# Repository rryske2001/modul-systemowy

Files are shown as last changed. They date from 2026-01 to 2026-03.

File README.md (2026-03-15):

# Moduł Systemowy HD44780 LCD Driver & PCB Adapter Collection





## 📖 O projekcie

Niniejsze repozytorium zawiera kompleksowe rozwiązanie dla obsługi popularnych wyświetlaczy znakowych LCD opartych na sterowniku **HD44780**. Projekt składa się z dwóch głównych filarów:
1.  **Warstwa sprzętowa:** Projekty płytek drukowanych (PCB) wykonane w środowisku **KiCad**, służące jako adaptery i moduły interfejsowe dla wyświetlaczy 16x2, 20x4 oraz 40x2.
2.  **Warstwa programowa:** Biblioteki sterowników napisane w języku C, obsługujące różne tryby komunikacji (I2C, 4-bit, 8-bit) ze szczególnym naciskiem na optymalizację (odczyt flagi zajętości - Busy Flag).

---

## 🛠️ Funkcjonalności

### 🔌 Hardware (Projekty PCB)
Projekty płytek zostały przygotowane w programie **KiCad**. Repozytorium zawiera pliki produkcyjne oraz źródłowe dla kilku wariantów:
* **Wersje jedno- i dwuwarstwowe:** Dostosowane do różnych metod produkcji (domowe trawienie vs profesjonalna produkcja).
* **Uniwersalność:** Obsługa popularnych formatów wyświetlaczy: 16x2, 20x4 oraz 40x2.
* **Adaptery I2C:** Projekty integrujące ekspandery portów (np. PCF8574) bezpośrednio z wyświetlaczem, co redukuje liczbę wymaganych pinów mikrokontrolera.

### 💻 Software (Sterowniki)
Kod źródłowy zawiera implementację sterowników w różnych konfiguracjach sprzętowych:
* **Obsługa I2C:** Sterowanie poprzez ekspander (PCF8574), idealne dla systemów z ograniczoną liczbą GPIO.
* **Tryb równoległy (4-bit i 8-bit):** Klasyczne sterowanie bezpośrednie.
* **Busy Flag Check:** Zaimplementowany mechanizm odczytu flagi zajętości sterownika HD44780. Pozwala to na uniknięcie sztywnych opóźnień (`delay`), co znacząco zwiększa wydajność całego systemu wbudowanego.
* **Interfejs szeregowy:** Alternatywne metody komunikacji.

---

## 📂 Struktura Repozytorium

Poniżej znajduje się opis zawartości kluczowych katalogów:

### Projekty KiCad
* `/Wersja_z_I2C_8bit_...` - Projekt dwuwarstwowej płytki z integracją I2C.
* `/Wersja_16x2_20x4_...` - Uniwersalna płytka jednowarstwowa dla standardowych wyświetlaczy.
* `/wersja_ostateczna_wyswietlacz_pcf_v1` - Finalna wersja adaptera z układem PCF.

### Kod Źródłowy
* `/wyswietlacz_interfejs_4_bit_BusyFlag` - Sterownik 4-bitowy z odczytem BF.
* `/testy_z_ekspanderem_pcf` - Kod testowy dla komunikacji I2C.
* `/wyswietlacz_interfejs_8_bit` - Podstawowa obsługa w trybie 8-bitowym.

---

## 🔧 Technologie i Narzędzia

* **Projektowanie PCB:** KiCad EDA
* **Język programowania:** C (Embedded)
* **Hardware:** Wyświetlacze HD44780, Ekspandery PCF8574
* **Protokoły:** I2C, Parallel Interface

---

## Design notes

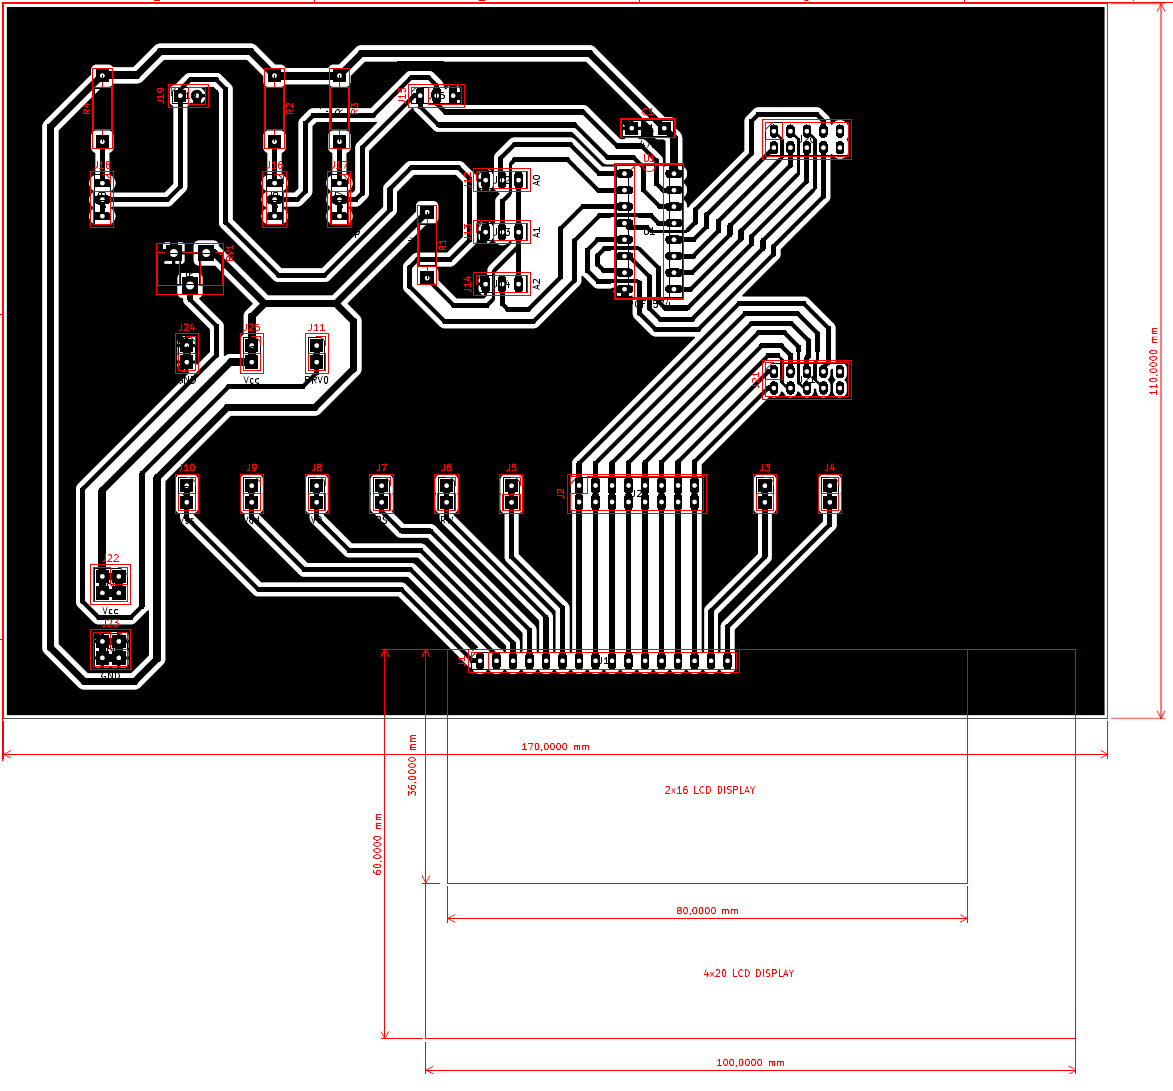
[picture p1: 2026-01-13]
plytki/wersja_ostateczna_wyswietlacz_pcf_v1/plots/wersja_ostateczna_wyswietlacz_pcf_v1.png

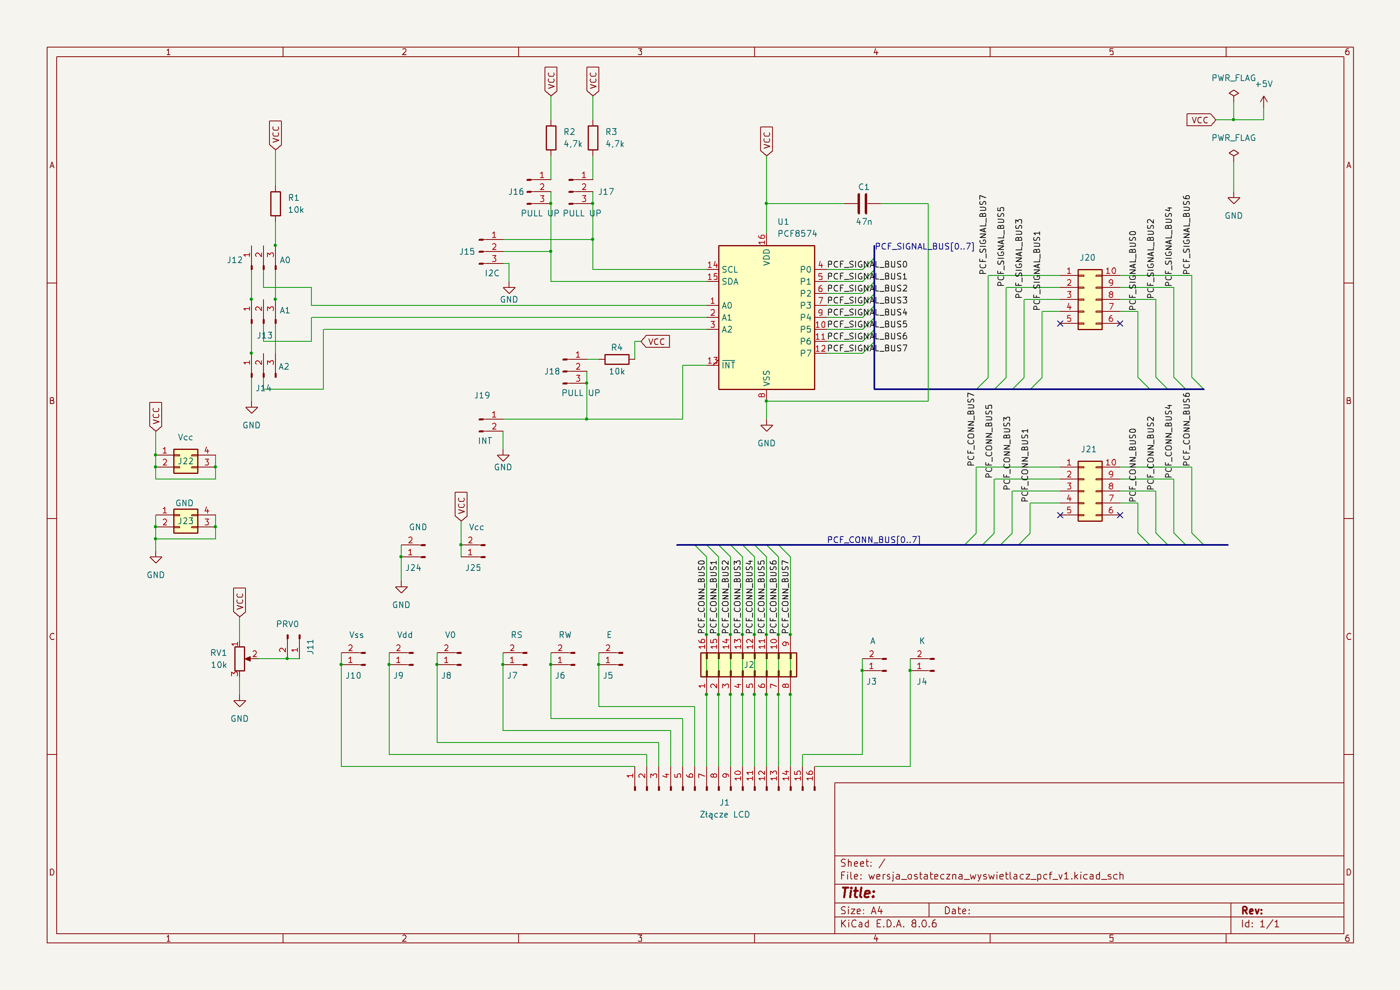
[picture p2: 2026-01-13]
plytki/wersja_ostateczna_wyswietlacz_pcf_v1/plots/wersja_ostateczna_wyswietlacz_pcf_v1_Schemat.png

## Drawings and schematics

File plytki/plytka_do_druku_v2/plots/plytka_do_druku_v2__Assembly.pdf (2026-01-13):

1 | 2 | 3 | 4 | 5 | 6

A

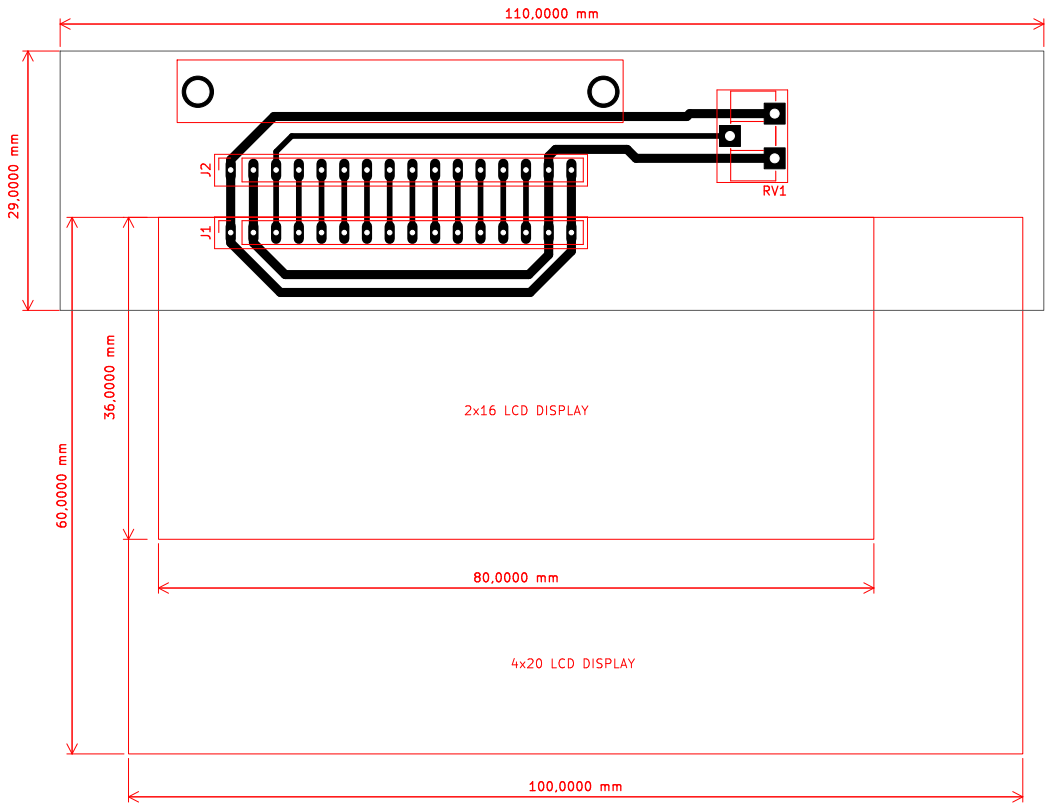
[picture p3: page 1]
D Date: KiCad; E.D.A. 8.0.6 Size: A4; Rev:; 2x16 LCD DISPLAY J2 J1

4x20 LCD DISPLAY ³⁶,0000 mm

Id: 1/1 Title: File: plytka_do_druku_v2.kicad_pcb Sheet:

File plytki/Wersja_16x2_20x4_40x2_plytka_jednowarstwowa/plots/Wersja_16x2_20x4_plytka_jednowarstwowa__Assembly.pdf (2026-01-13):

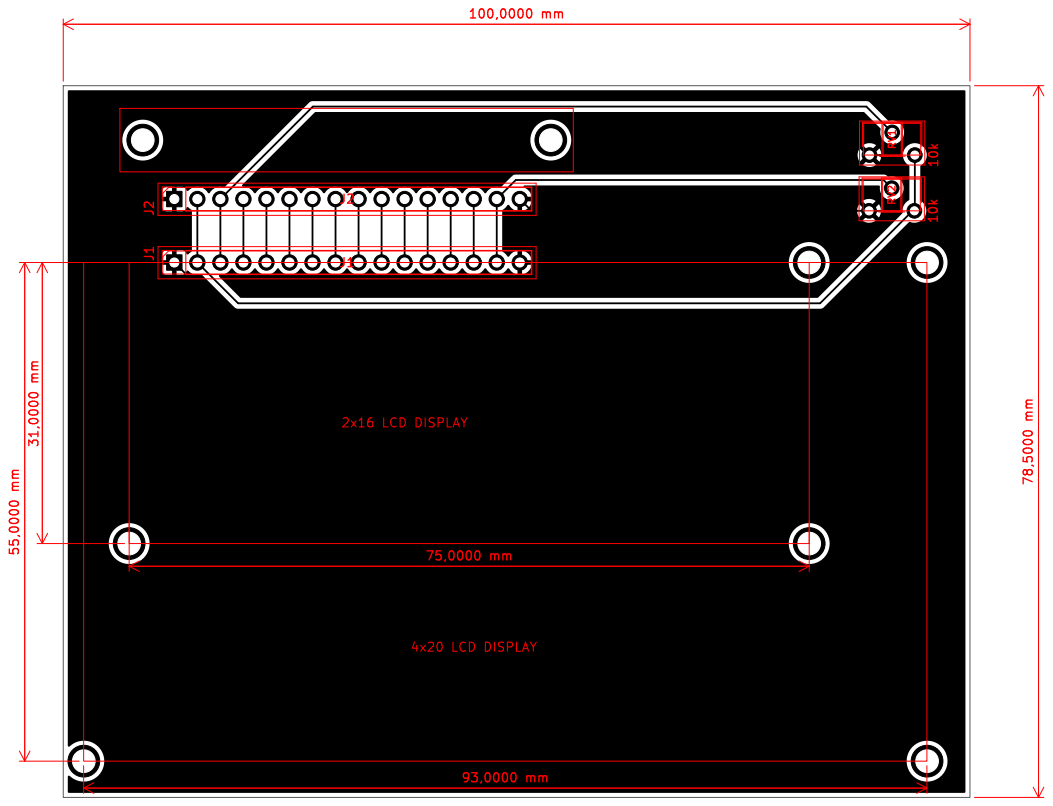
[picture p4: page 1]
D Date: KiCad; E.D.A. 8.0.6 Size: A4; Rev:; 10kRV¹; 10kRV² 4x20 LCD DISPLAY; 2x16 LCD DISPLAY J1 J2

Id: 1/1 Title: File: Wersja_16x2_20x4_plytka_jednowarstwowa.kicad_pcb Sheet:

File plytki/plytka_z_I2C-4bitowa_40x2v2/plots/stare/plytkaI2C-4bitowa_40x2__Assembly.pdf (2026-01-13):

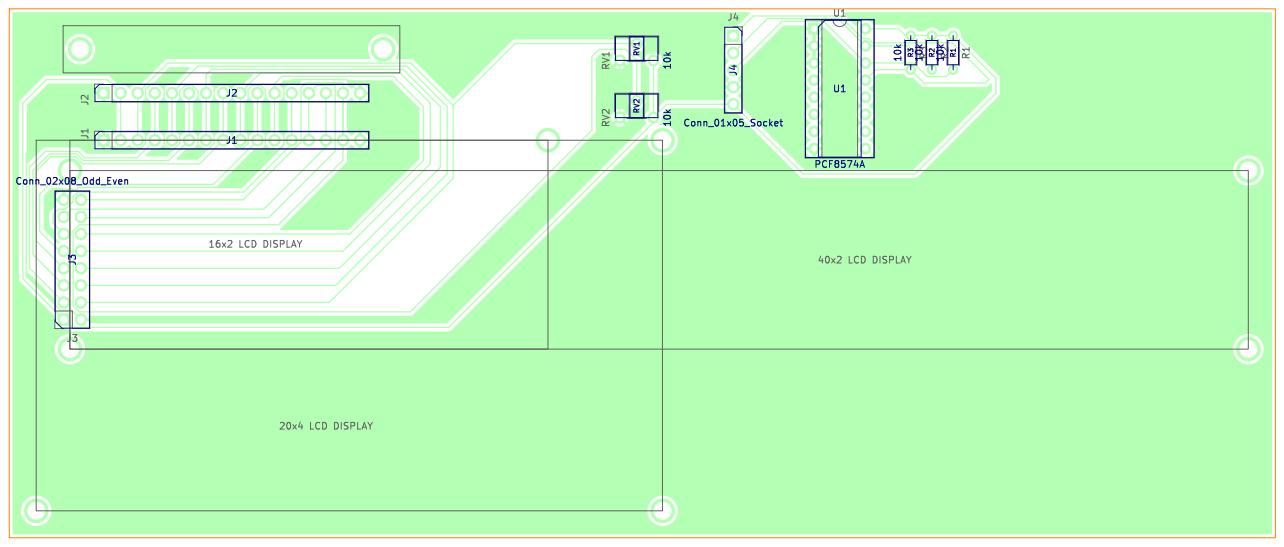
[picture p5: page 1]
40x2 LCD DISPLAY; 20x4 LCD DISPLAY; 16x2 LCD DISPLAY; RV² J2; RV¹; D Date: KiCad; E.D.A. 8.0.6 Size: A4; Rev:; Id: 1/1 Title: File: plytkaI2C-4bitowa_40x2.kicad_pcb Sheet: ¹⁰k; R¹ Conn_01x05_Socket J4; Conn_02x08_Odd_Even J3; 10kRV²; 10kRV¹; PCF8574A U1

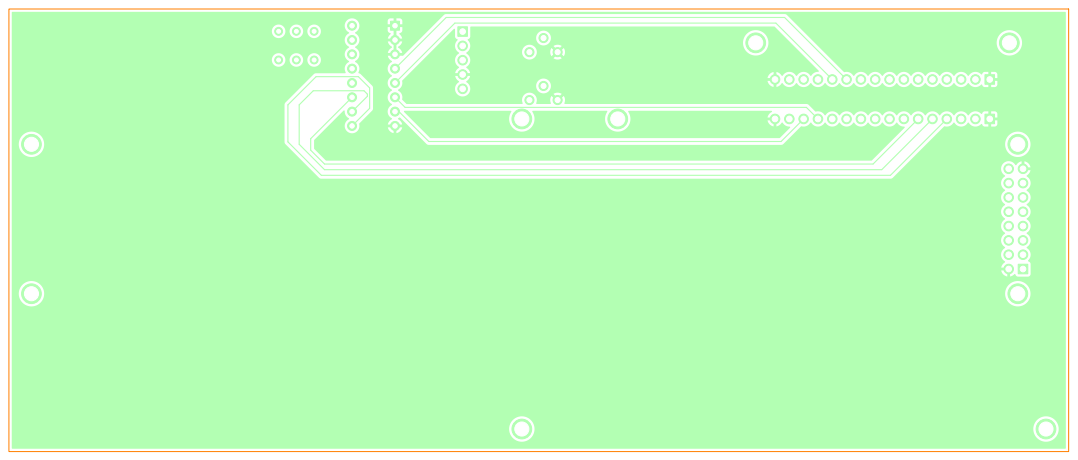
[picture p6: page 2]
D Date: KiCad; E.D.A. 8.0.6 Size: A4; Rev:

Id: 1/1 Title: File: plytkaI2C-4bitowa_40x2.kicad_pcb Sheet:

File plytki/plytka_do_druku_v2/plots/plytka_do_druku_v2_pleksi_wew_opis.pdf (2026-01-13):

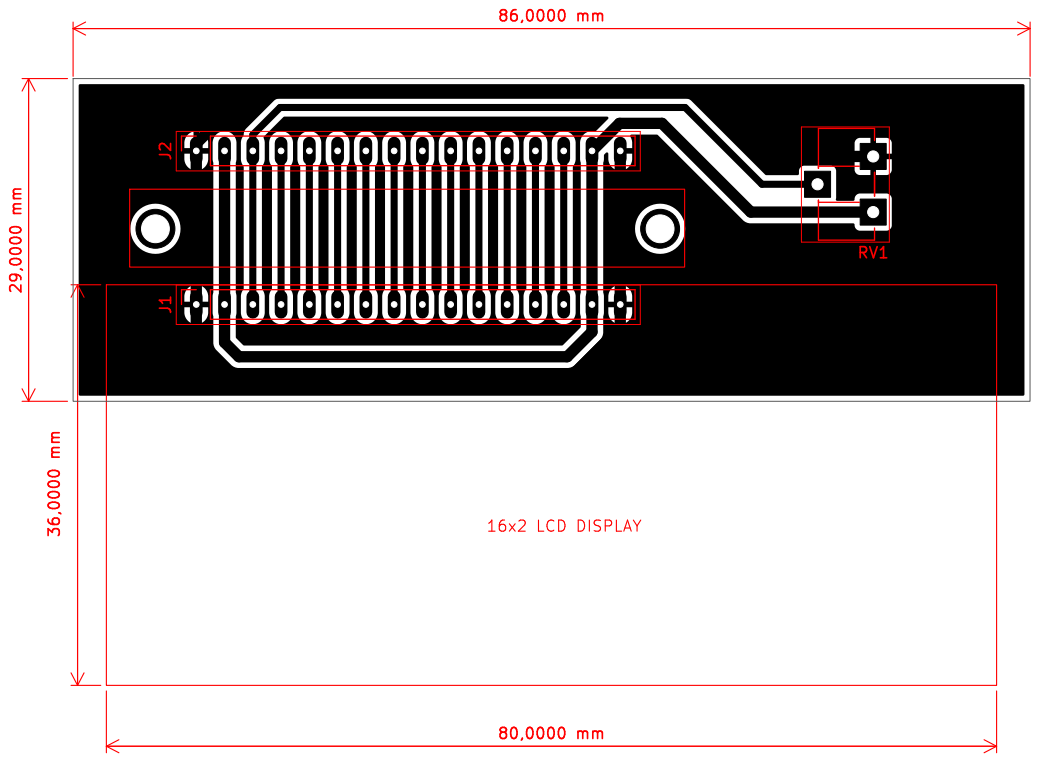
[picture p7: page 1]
D Date: KiCad; E.D.A. 8.0.6 Size: A4; Rev:; 16x2 LCD DISPLAY J2 J1

Id: 1/1 Title: File: plytka_do_druku_v2_pleksi_wew.kicad_pcb Sheet:

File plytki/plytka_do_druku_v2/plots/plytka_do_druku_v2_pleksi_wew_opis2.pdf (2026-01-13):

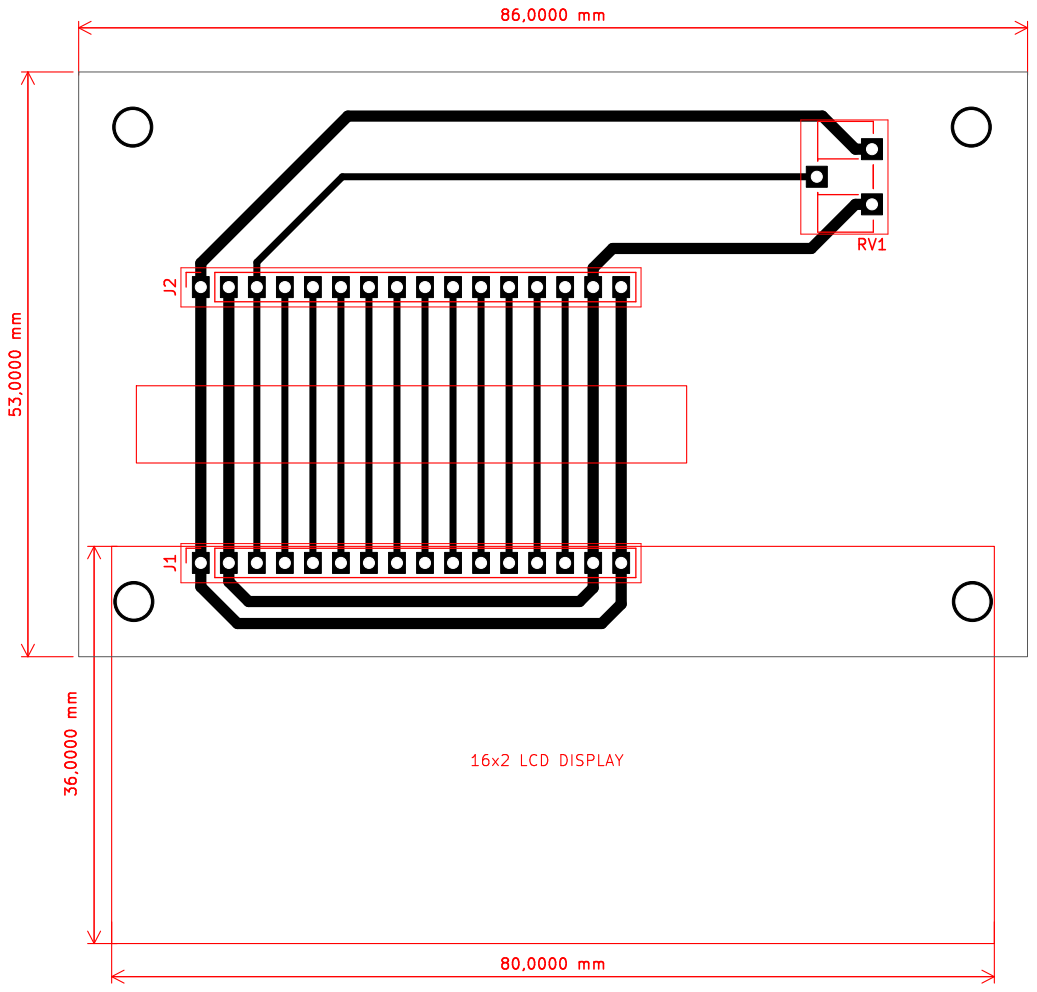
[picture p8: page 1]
D Date: KiCad; E.D.A. 8.0.6 Size: A4; Rev:; Id: 1/1 Title: File: plytka_do_druku_v2_pleksi_wew.kicad_pcb Sheet: ¹⁶x2 LCD DISPLAY J2 J1

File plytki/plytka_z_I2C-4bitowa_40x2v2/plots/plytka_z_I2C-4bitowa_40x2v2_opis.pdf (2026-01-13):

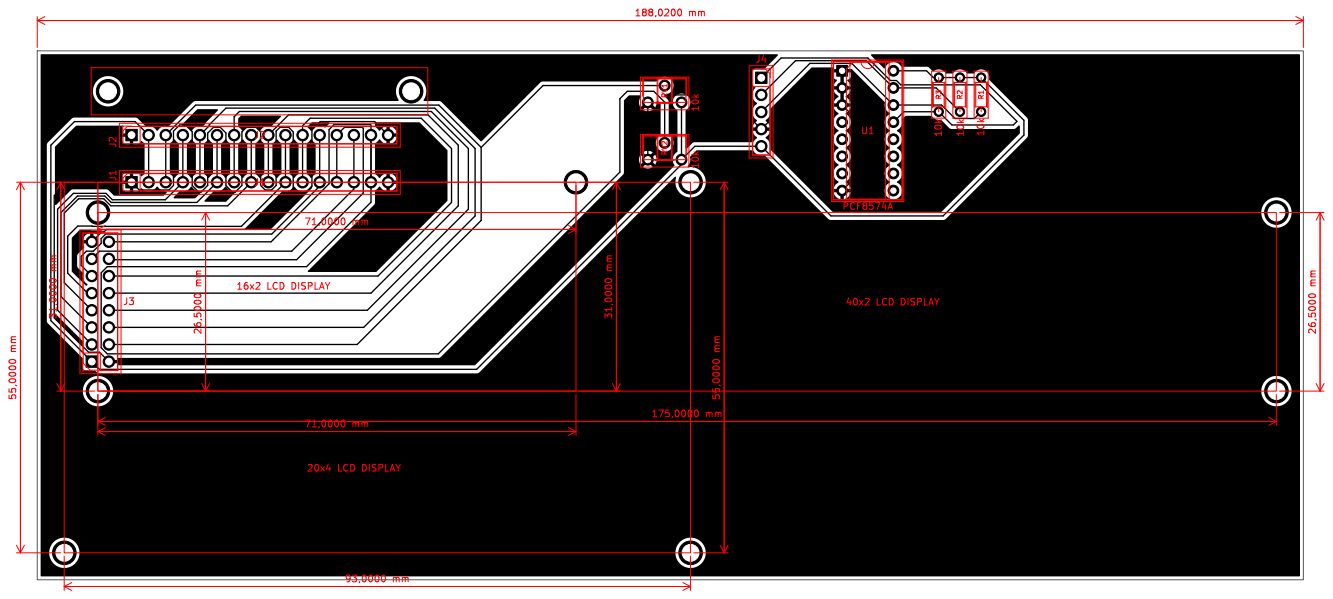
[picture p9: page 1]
D Date: KiCad; E.D.A. 8.0.6 Size: A4; Rev:; Id: 1/1 Title: File: plytka_z_I2C-4bitowa_40x2v2.kicad_pcb Sheet: ¹⁰k R³; 10kRV²; PCF8574A U1 J2; 10kRV¹; 10k R¹ 40x2 LCD DISPLAY; 20x4 LCD DISPLAY; 16x2 LCD DISPLAY

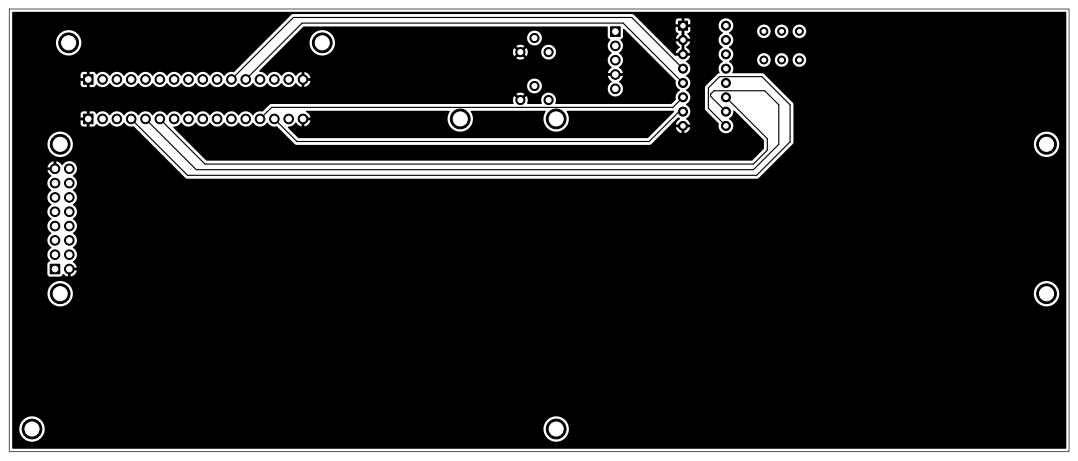
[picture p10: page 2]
D Date: KiCad; E.D.A. 8.0.6 Size: A4; Rev:

Id: 1/1 Title: File: plytka_z_I2C-4bitowa_40x2v2.kicad_pcb Sheet:

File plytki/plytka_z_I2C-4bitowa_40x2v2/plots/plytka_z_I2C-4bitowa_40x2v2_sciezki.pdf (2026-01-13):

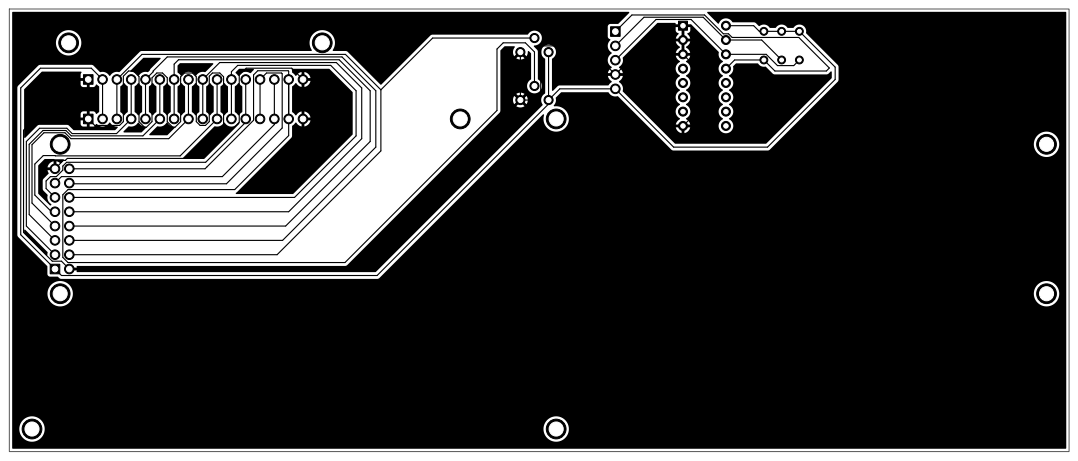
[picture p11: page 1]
D Date: KiCad; E.D.A. 8.0.6 Size: A4; Rev:

Id: 1/1 Title: File: plytka_z_I2C-4bitowa_40x2v2.kicad_pcb Sheet:

D Date: KiCad; E.D.A. 8.0.6 Size: A4; Rev:

Id: 1/1 Title: File: plytka_z_I2C-4bitowa_40x2v2.kicad_pcb Sheet:

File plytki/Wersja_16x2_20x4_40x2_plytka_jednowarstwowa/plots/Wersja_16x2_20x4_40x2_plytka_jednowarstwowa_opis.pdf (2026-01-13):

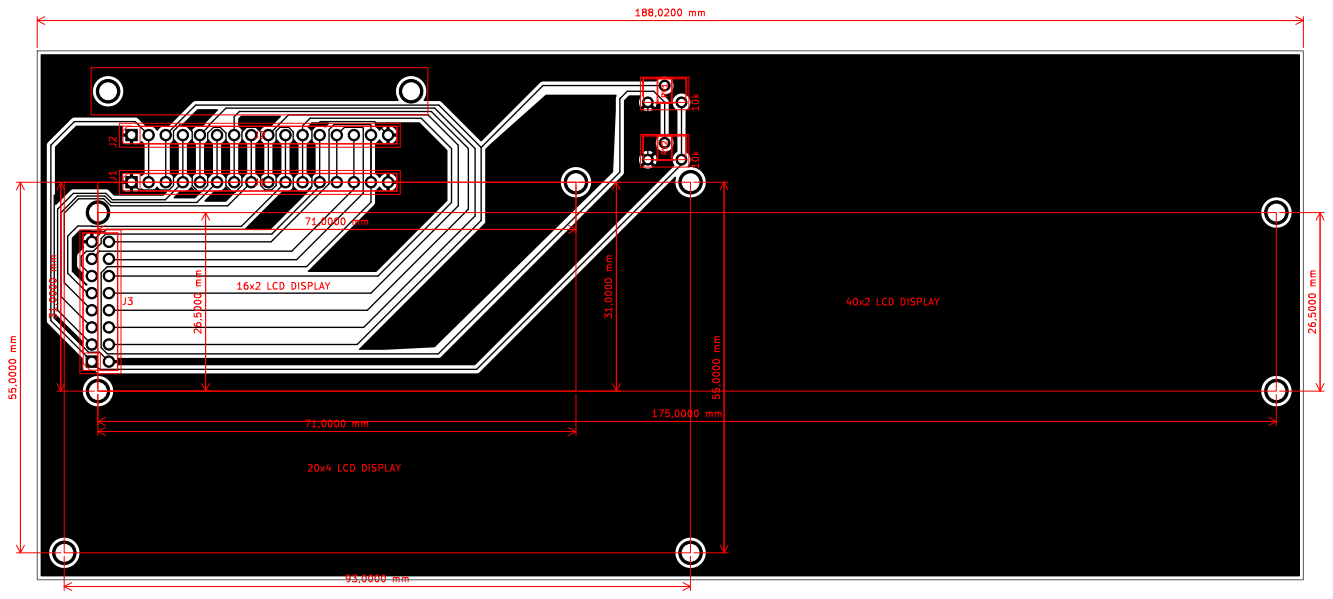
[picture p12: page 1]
D Date: KiCad; E.D.A. 8.0.6 Size: A4; Rev:; 10kRV²; 10kRV¹; 40x2 LCD DISPLAY; 20x4 LCD DISPLAY; 16x2 LCD DISPLAY

Id: 1/1 Title: File: Wersja_16x2_20x4_40x2_plytka_jednowarstwowa.kicad_pcb Sheet:

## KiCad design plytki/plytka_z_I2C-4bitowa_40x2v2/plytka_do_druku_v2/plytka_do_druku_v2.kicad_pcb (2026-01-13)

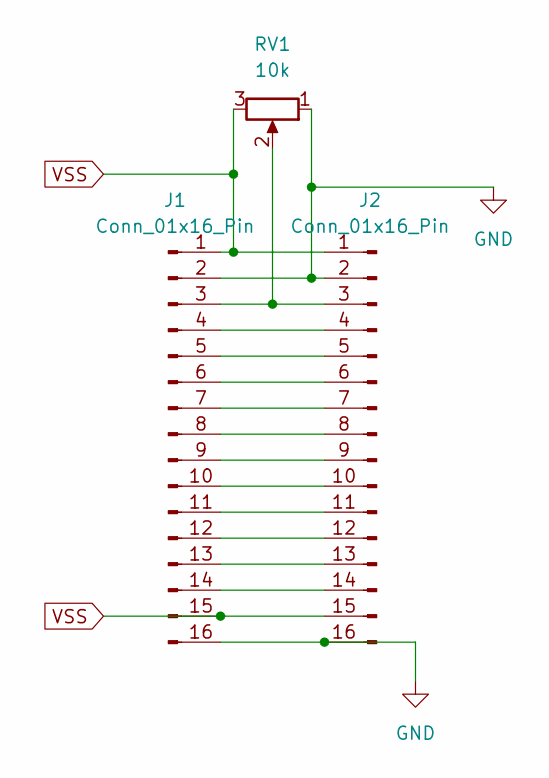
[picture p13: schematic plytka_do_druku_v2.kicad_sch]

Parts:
J1: Conn_01x16_Pin; PinSocket_1x16_P2.54mm_Vertical
J2: Conn_01x16_Pin; waski
RV1: 10k; Potentiometer_Alps_RK09Y11_Single_Horizontal

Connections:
GND: J1.2, J1.16, J2.2, J2.16, RV1.1
unnamed: J1.3, J2.3, RV1.2
unnamed: J1.4, J2.4
unnamed: J1.5, J2.5
unnamed: J1.6, J2.6
unnamed: J1.7, J2.7
unnamed: J1.8, J2.8
unnamed: J1.9, J2.9
unnamed: J1.10, J2.10
unnamed: J1.11, J2.11
unnamed: J1.12, J2.12
unnamed: J1.13, J2.13
unnamed: J1.14, J2.14
VSS: J1.1, J1.15, J2.1, J2.15, RV1.3

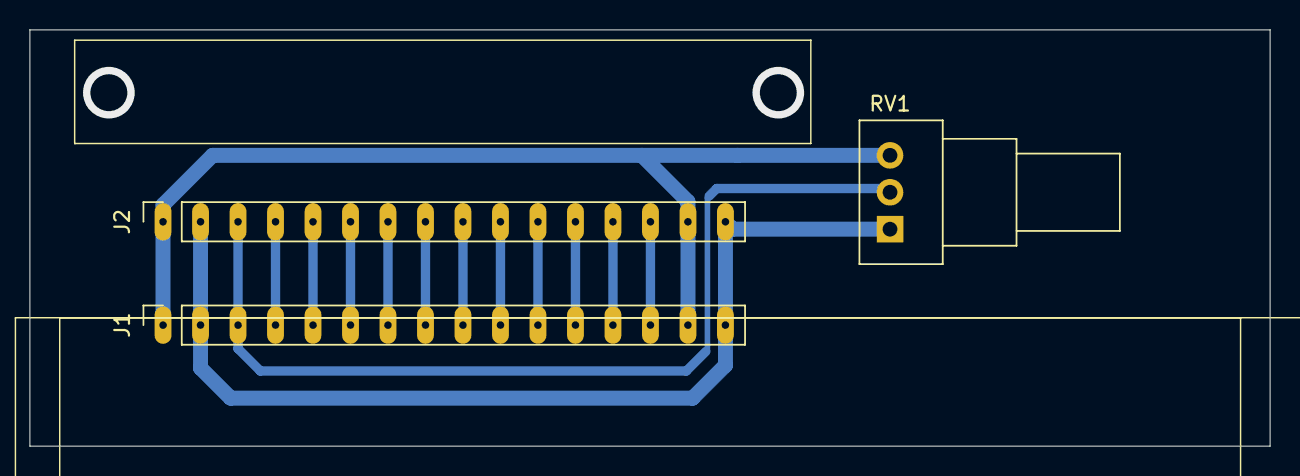
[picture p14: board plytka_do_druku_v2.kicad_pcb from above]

Board: 2 copper layers, 84.0 x 28.2 mm, 3 parts (0 on the bottom side), 14 nets.

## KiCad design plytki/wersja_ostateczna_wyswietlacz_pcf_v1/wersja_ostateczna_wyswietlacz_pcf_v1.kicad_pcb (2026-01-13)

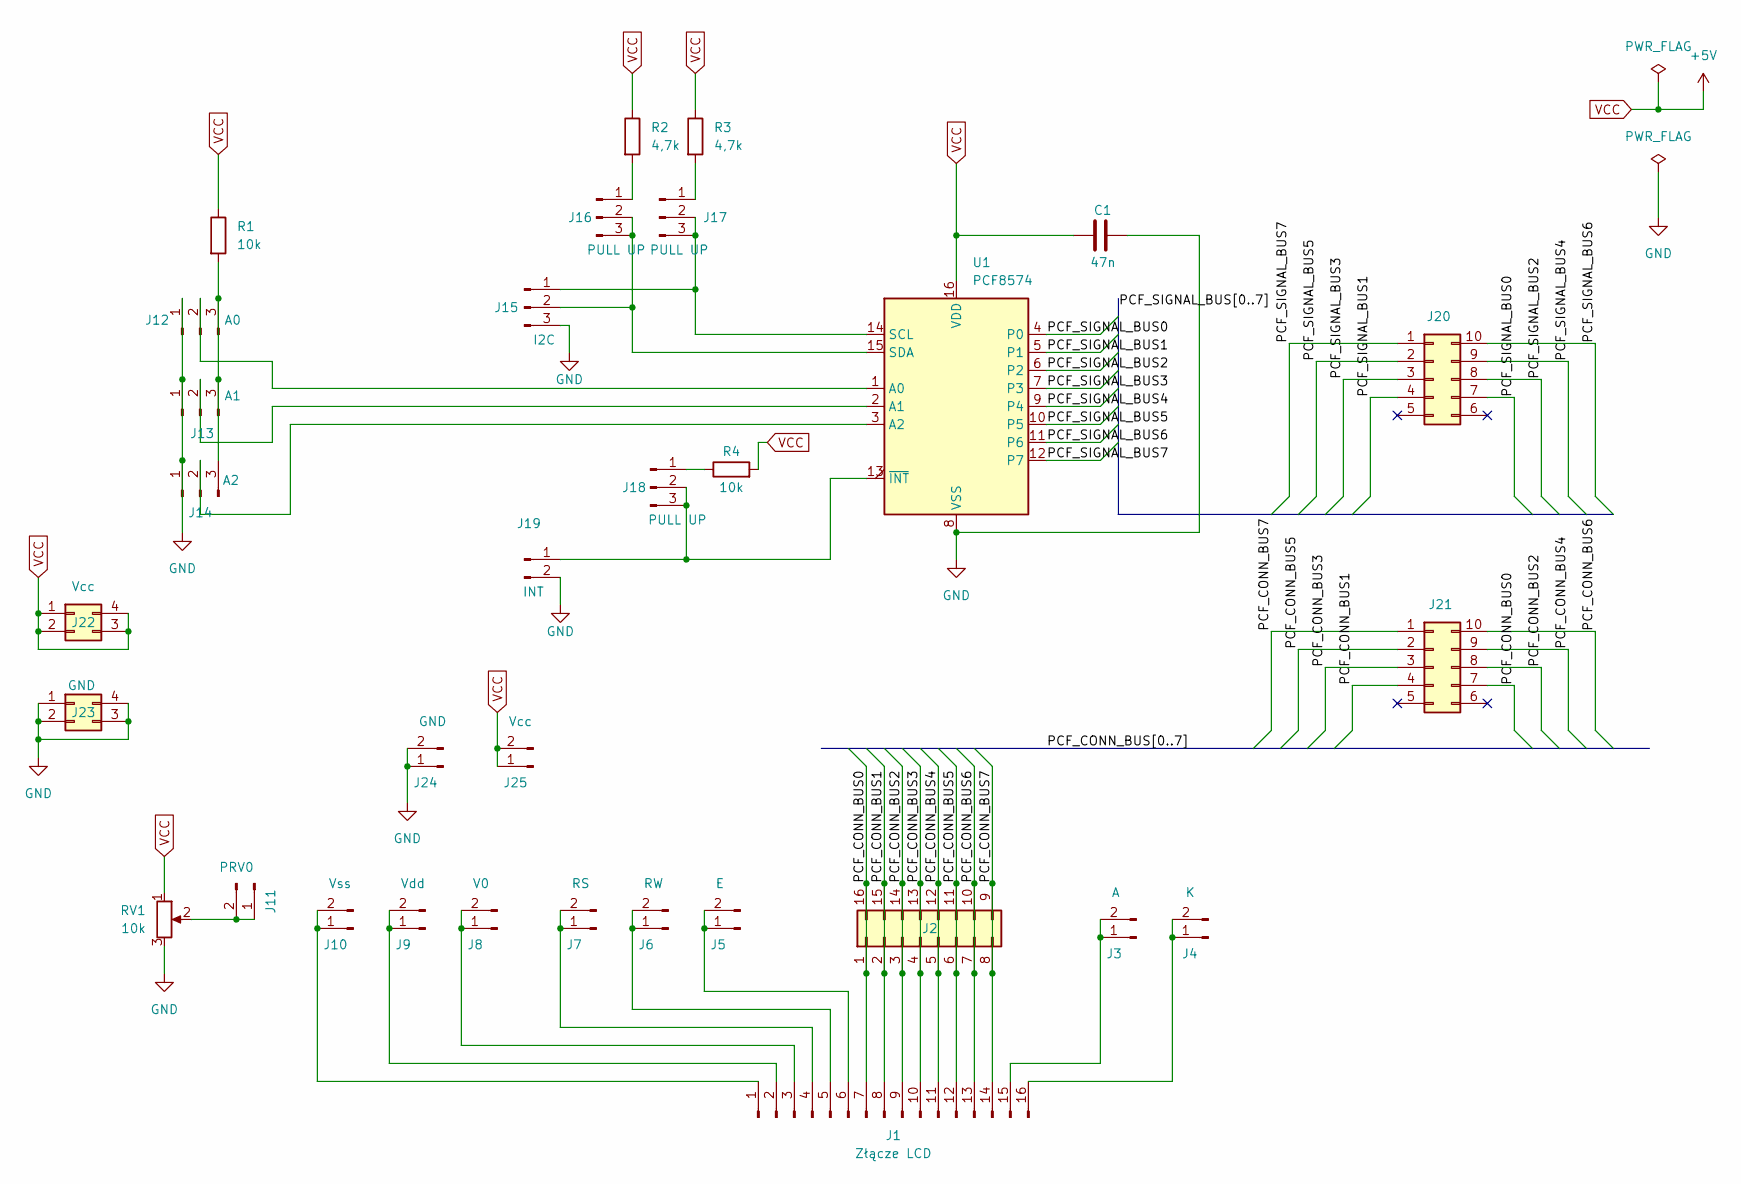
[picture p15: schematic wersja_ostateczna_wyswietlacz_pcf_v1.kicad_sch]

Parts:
C1: 47n; C_Disc_D8.0mm_W2.5mm_P5.00mm
J1: Złącze LCD; PinSocket_1x16_P2.54mm_Vertical
J2: Conn_02x08_Counter_Clockwise; PinSocket_2x08_P2.54mm_Vertical
J3: A; PinSocket_1x02_P2.54mm_Vertical_square
J4: K; PinSocket_1x02_P2.54mm_Vertical_square
J5: E; PinSocket_1x02_P2.54mm_Vertical_square
J6: RW; PinSocket_1x02_P2.54mm_Vertical_square
J7: RS; PinSocket_1x02_P2.54mm_Vertical_square
J8: V0; PinSocket_1x02_P2.54mm_Vertical_square
J9: Vdd; PinSocket_1x02_P2.54mm_Vertical_square
J10: Vss; PinSocket_1x02_P2.54mm_Vertical_square
J11: PRV0; PinSocket_1x02_P2.54mm_Vertical_square
J12: A0; PinSocket_1x03_P2.54mm_Vertical
J13: A1; PinSocket_1x03_P2.54mm_Vertical
J14: A2; PinSocket_1x03_P2.54mm_Vertical
J15: I2C; PinSocket_1x03_P2.54mm_Vertical
J16, J17, J18: PULL UP; PinSocket_1x03_P2.54mm_Vertical
J19: INT; PinSocket_1x02_P2.54mm_Vertical
J20, J21: Conn_02x05_Counter_Clockwise; PinSocket_2x05_P2.54mm_Vertical_LEZKA
J22: Vcc; PinSocket_2x02_P2.54mm_Vertical
J23: GND; PinSocket_2x02_P2.54mm_Vertical
J24: GND; PinSocket_1x02_P2.54mm_Vertical_square
J25: Vcc; PinSocket_1x02_P2.54mm_Vertical_square
R1, R4: 10k; R_Axial_DIN0207_L6.3mm_D2.5mm_P10.16mm_Horizontal_square
R2, R3: 4,7k; R_Axial_DIN0207_L6.3mm_D2.5mm_P10.16mm_Horizontal_square
RV1: 10k; Potentiometer_ACP_CA9-H5_Horizontal
U1: PCF8574; DIP-16_W7.62mm_Socket_LongPads

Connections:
/PCF_CONN_BUS0: J1.7, J2.1, J2.16, J21.7
/PCF_CONN_BUS1: J1.8, J2.2, J2.15, J21.4
/PCF_CONN_BUS2: J1.9, J2.3, J2.14, J21.8
/PCF_CONN_BUS3: J1.10, J2.4, J2.13, J21.3
/PCF_CONN_BUS4: J1.11, J2.5, J2.12, J21.9
/PCF_CONN_BUS5: J1.12, J2.6, J2.11, J21.2
/PCF_CONN_BUS6: J1.13, J2.7, J2.10, J21.10
/PCF_CONN_BUS7: J1.14, J2.8, J2.9, J21.1
/PCF_SIGNAL_BUS0: J20.7, U1.4 (P0)
/PCF_SIGNAL_BUS1: J20.4, U1.5 (P1)
/PCF_SIGNAL_BUS2: J20.8, U1.6 (P2)
/PCF_SIGNAL_BUS3: J20.3, U1.7 (P3)
/PCF_SIGNAL_BUS4: J20.9, U1.9 (P4)
/PCF_SIGNAL_BUS5: J20.2, U1.10 (P5)
/PCF_SIGNAL_BUS6: J20.10, U1.11 (P6)
/PCF_SIGNAL_BUS7: J20.1, U1.12 (P7)
GND: C1.1, J12.1, J13.1, J14.1, J15.3, J19.2, J23.1, J23.2, J23.3, J23.4, J24.1, J24.2, RV1.3, U1.8 (VSS)
unnamed: J1.1, J10.1, J10.2
unnamed: J1.2, J9.1, J9.2
unnamed: J1.3, J8.1, J8.2
unnamed: J1.4, J7.1, J7.2
unnamed: J1.5, J6.1, J6.2
unnamed: J1.6, J5.1, J5.2
unnamed: J1.15, J3.1, J3.2
unnamed: J1.16, J4.1, J4.2
unnamed: J11.1, J11.2, RV1.2
unnamed: J12.2, U1.1 (A0)
unnamed: J12.3, J13.3, J14.3, R1.2
unnamed: J13.2, U1.2 (A1)
unnamed: J14.2, U1.3 (A2)
unnamed: J15.1, J17.2, J17.3, U1.14 (SCL)
unnamed: J15.2, J16.2, J16.3, U1.15 (SDA)
unnamed: J16.1, R2.2
unnamed: J17.1, R3.2
unnamed: J18.1, R4.1
unnamed: J18.2, J18.3, J19.1, U1.13 (~INT)
VCC: C1.2, J22.1, J22.2, J22.3, J22.4, J25.1, J25.2, R1.1, R2.1, R3.1, R4.2, RV1.1, U1.16 (VDD)

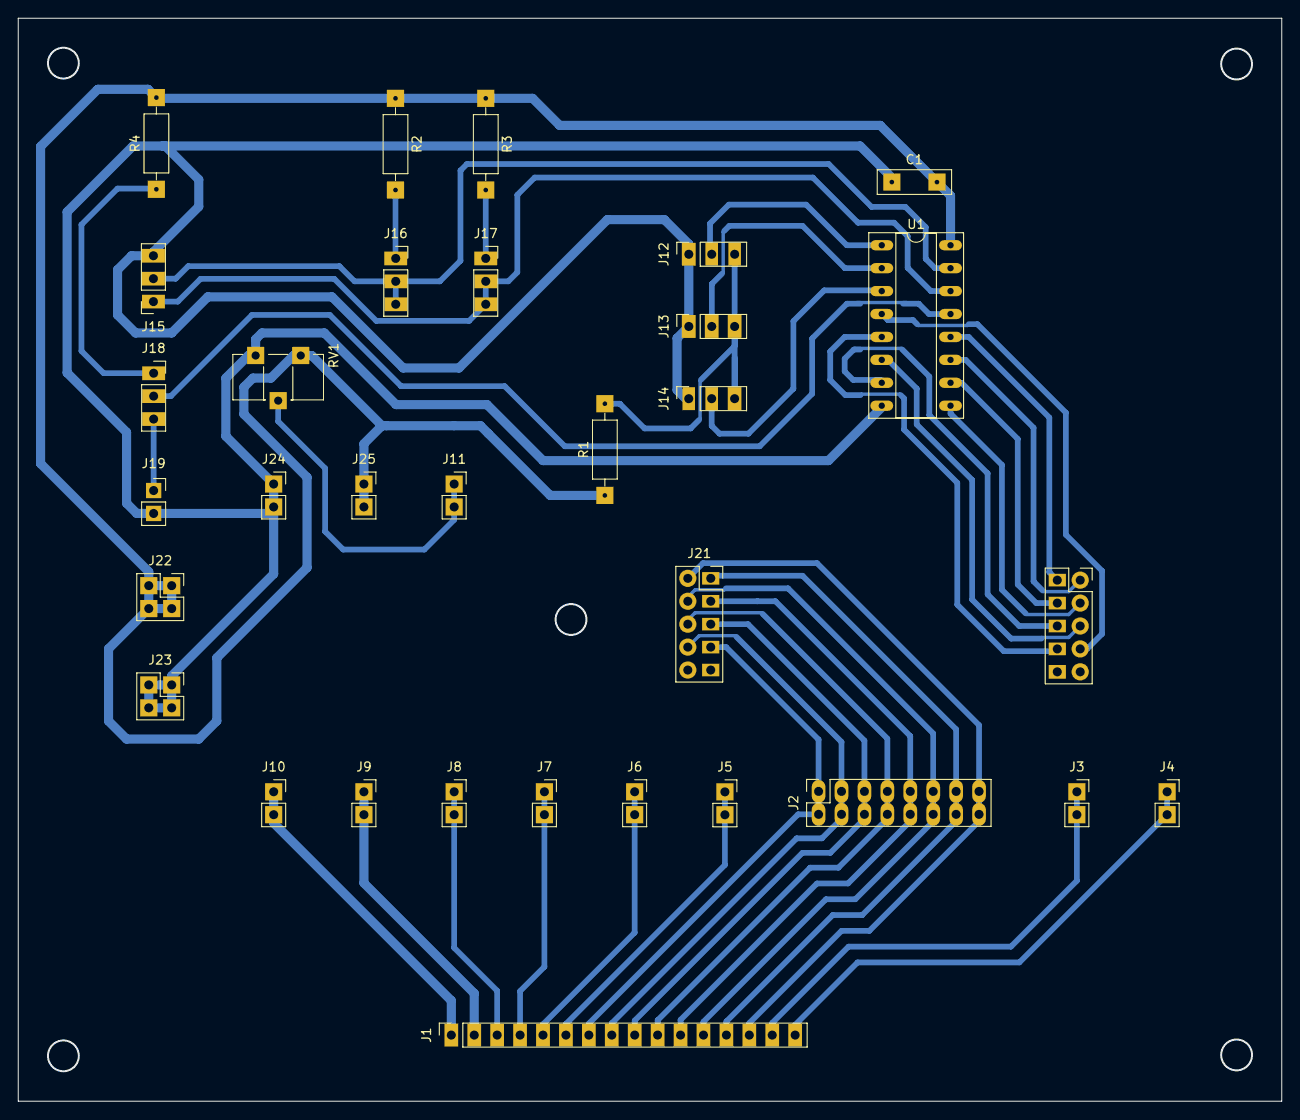
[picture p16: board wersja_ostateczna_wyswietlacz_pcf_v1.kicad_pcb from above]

Board: 2 copper layers, 140.0 x 120.0 mm, 32 parts (0 on the bottom side), 37 nets.

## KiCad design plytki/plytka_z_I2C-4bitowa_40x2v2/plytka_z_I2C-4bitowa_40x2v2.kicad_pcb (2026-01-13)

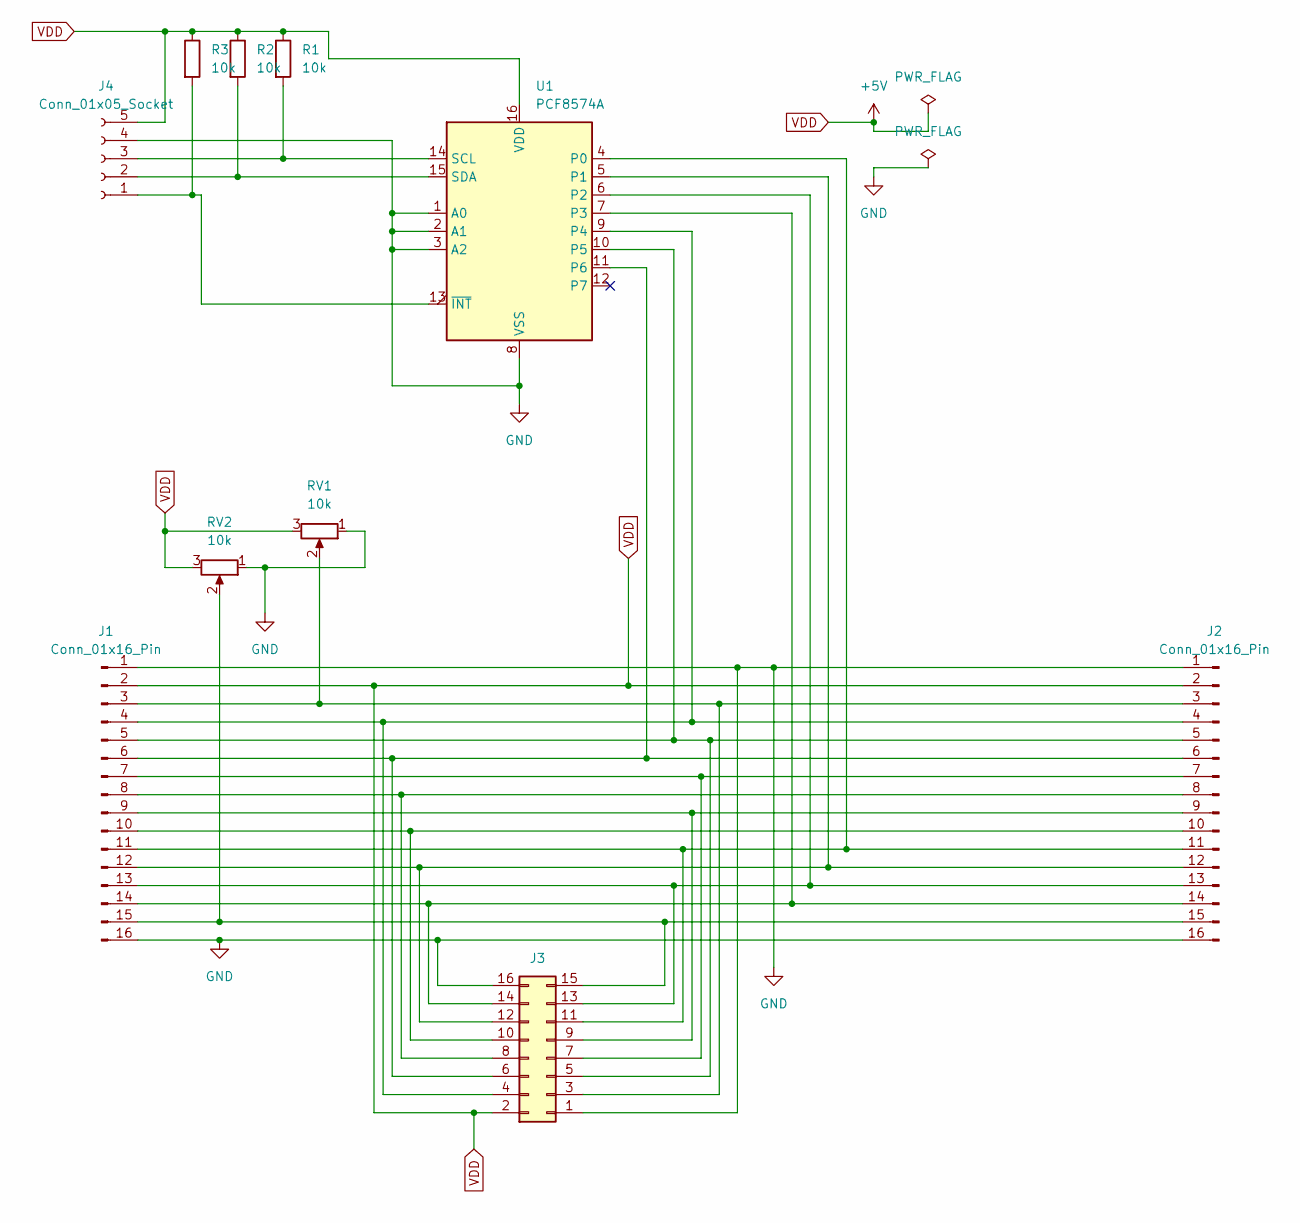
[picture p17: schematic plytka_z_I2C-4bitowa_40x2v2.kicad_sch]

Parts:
J1, J2: Conn_01x16_Pin; PinSocket_1x16_P2.54mm_Vertical
J3: Conn_02x08_Odd_Even; PinSocket_2x08_P2.54mm_Vertical
J4: Conn_01x05_Socket; PinSocket_1x05_P2.54mm_Vertical
R1, R2, R3: 10k; R_Axial_DIN0204_L3.6mm_D1.6mm_P5.08mm_Horizontal
RV1, RV2: 10k; Potentiometer_ACP_CA6-H2,5_Horizontal
U1: PCF8574A; DIP-16_W7.62mm_Socket

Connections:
GND: J1.1, J1.16, J2.1, J2.16, J3.1, J3.16, J4.4 (Pin_SDA), RV1.1, RV2.1, U1.1 (A0), U1.2 (A1), U1.3 (A2), U1.8 (VSS)
unnamed: J1.3, J2.3, J3.3, RV1.2
unnamed: J1.4, J2.4, J3.4, U1.9 (P4)
unnamed: J1.5, J2.5, J3.5, U1.10 (P5)
unnamed: J1.6, J2.6, J3.6, U1.11 (P6)
unnamed: J1.7, J2.7, J3.7
unnamed: J1.8, J2.8, J3.8
unnamed: J1.9, J2.9, J3.9
unnamed: J1.10, J2.10, J3.10
unnamed: J1.11, J2.11, J3.11, U1.4 (P0)
unnamed: J1.12, J2.12, J3.12, U1.5 (P1)
unnamed: J1.13, J2.13, J3.13, U1.6 (P2)
unnamed: J1.14, J2.14, J3.14, U1.7 (P3)
unnamed: J1.15, J2.15, J3.15, RV2.2
unnamed: J4.2 (Pin_GND), R2.2, U1.15 (SDA)
unnamed: J4.3 (Pin_SCL), R1.2, U1.14 (SCL)
unnamed: J4.1 (Pin_VDD), R3.2, U1.13 (~INT)
VDD: J1.2, J2.2, J3.2, J4.5 (Pin_INT), R1.1, R2.1, R3.1, RV1.3, RV2.3, U1.16 (VDD)

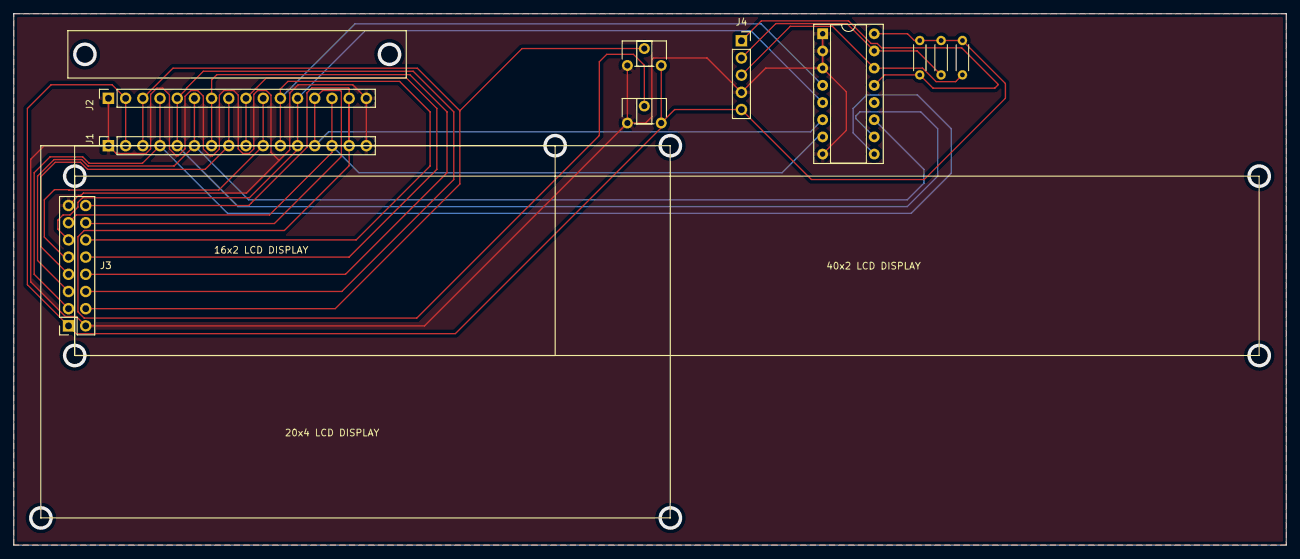
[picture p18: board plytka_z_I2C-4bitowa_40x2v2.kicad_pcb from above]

Board: 2 copper layers, 188.0 x 78.5 mm, 10 parts (0 on the bottom side), 18 nets.

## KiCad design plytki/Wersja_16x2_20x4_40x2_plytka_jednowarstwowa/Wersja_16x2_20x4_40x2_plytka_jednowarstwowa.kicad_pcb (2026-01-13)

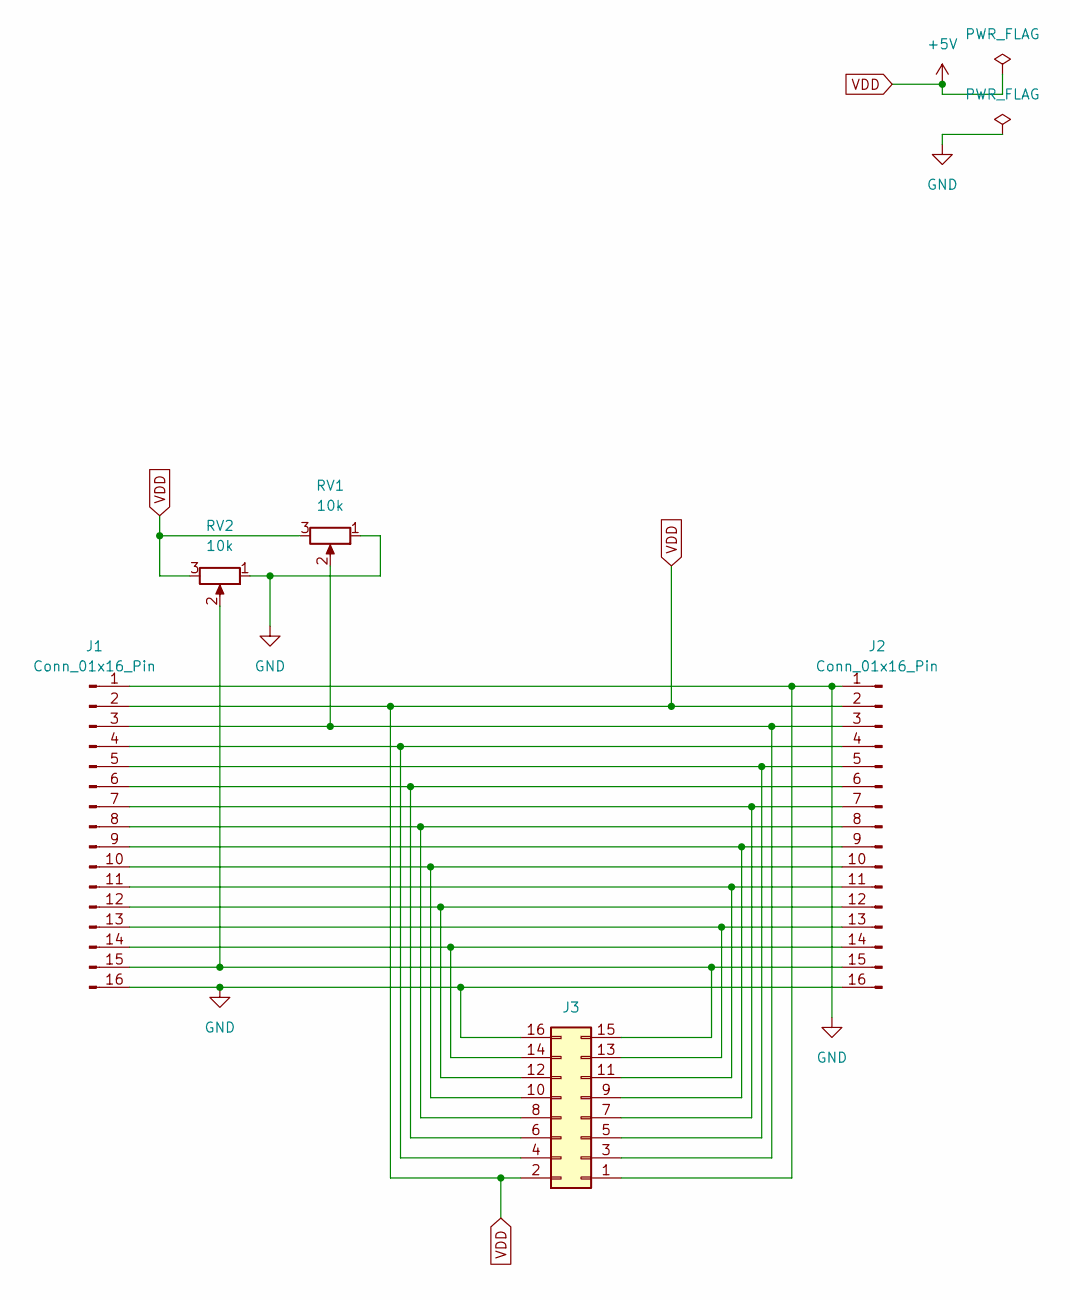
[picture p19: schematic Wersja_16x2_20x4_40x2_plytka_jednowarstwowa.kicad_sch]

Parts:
J1, J2: Conn_01x16_Pin; PinSocket_1x16_P2.54mm_Vertical
J3: Conn_02x08_Odd_Even; PinSocket_2x08_P2.54mm_Vertical
RV1, RV2: 10k; Potentiometer_ACP_CA6-H2,5_Horizontal

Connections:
GND: J1.1, J1.16, J2.1, J2.16, J3.1, J3.16, RV1.1, RV2.1
unnamed: J1.3, J2.3, J3.3, RV1.2
unnamed: J1.4, J2.4, J3.4
unnamed: J1.5, J2.5, J3.5
unnamed: J1.6, J2.6, J3.6
unnamed: J1.7, J2.7, J3.7
unnamed: J1.8, J2.8, J3.8
unnamed: J1.9, J2.9, J3.9
unnamed: J1.10, J2.10, J3.10
unnamed: J1.11, J2.11, J3.11
unnamed: J1.12, J2.12, J3.12
unnamed: J1.13, J2.13, J3.13
unnamed: J1.14, J2.14, J3.14
unnamed: J1.15, J2.15, J3.15, RV2.2
VDD: J1.2, J2.2, J3.2, RV1.3, RV2.3

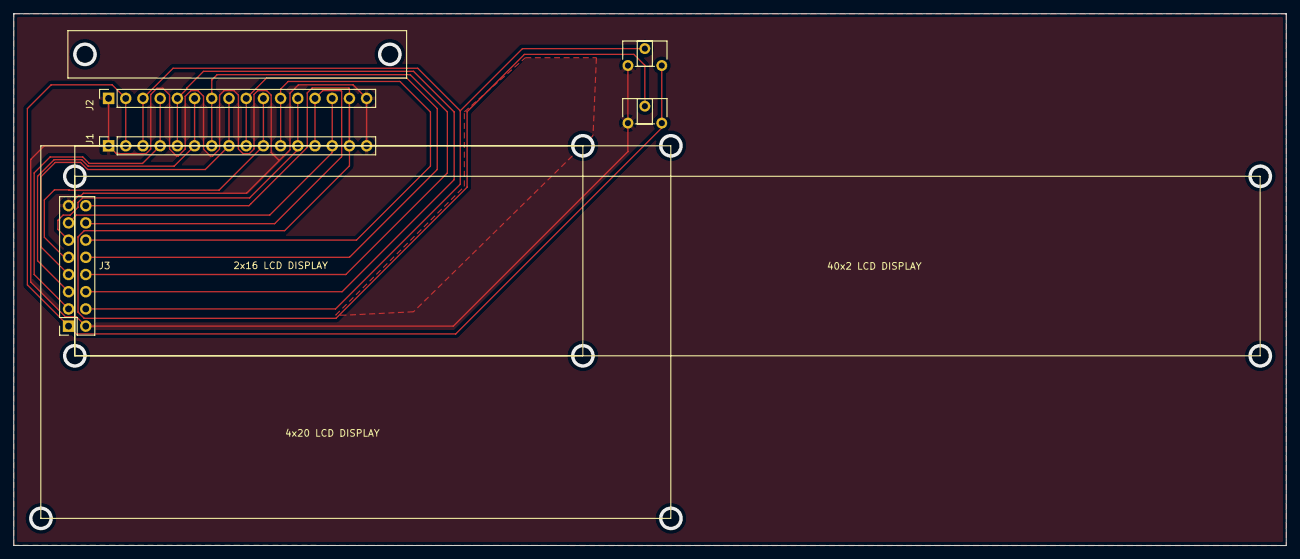
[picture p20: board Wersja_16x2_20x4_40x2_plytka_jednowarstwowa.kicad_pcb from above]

Board: 2 copper layers, 187.9 x 78.5 mm, 5 parts (0 on the bottom side), 15 nets.

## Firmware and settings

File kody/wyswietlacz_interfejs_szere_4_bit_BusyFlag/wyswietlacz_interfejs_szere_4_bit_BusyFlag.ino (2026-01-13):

#include <avr/io.h>
#include <util/delay.h>

#define PCF8574_ADDRESS 0x20

#define RS 0 
#define EN 1 
#define RW 2 

#define D4 4 
#define D5 5
#define D6 6
#define D7 7 

uint8_t to_send = 0;

uint16_t seconds = 0;

void I2C_Init() {
    TWSR = 0x00;
    TWBR = 0x48;
    TWCR = (1 << TWEN);
}

void I2C_Start() {
    TWCR = (1 << TWSTA) | (1 << TWEN) | (1 << TWINT);
    while (!(TWCR & (1 << TWINT)));
}

void I2C_Stop() {
    TWCR = (1 << TWSTO) | (1 << TWEN) | (1 << TWINT);
}

void I2C_Write(uint8_t data) {
    TWDR = data; 
    TWCR = (1 << TWEN) | (1 << TWINT); 
    while (!(TWCR & (1 << TWINT)));
}

void PCF8574_Write(uint8_t data) {
    I2C_Start();
    I2C_Write(PCF8574_ADDRESS << 1); 
    I2C_Write(data);                
    I2C_Stop();
    
}

uint8_t PCF8574_Read() { 
    uint8_t data;
    I2C_Start();
    I2C_Write((PCF8574_ADDRESS << 1) | 1); 
    TWCR = (1 << TWEN) | (1 << TWINT);     
    while (!(TWCR & (1 << TWINT)));
    data = TWDR;                          
    I2C_Stop();
    return data;
}

void lcd_enable(){
  to_send |= (1<<EN);
  PCF8574_Write(to_send);
  _delay_us(1); 
  to_send &= ~(1<<EN);
  PCF8574_Write(to_send);
  _delay_us(50);
}

void lcd_send(uint8_t data, uint8_t is_data){
  if(is_data) to_send |= (1<<RS);
  else to_send &= ~(1<<RS);
  
  to_send = (to_send&0b00001111)|(data&0b11110000);
  PCF8574_Write(to_send);
  lcd_enable();

  to_send = (to_send&0b00001111)|((data<< 4) &0b11110000 );
  PCF8574_Write(to_send);
  lcd_enable();

  wait_until_BS();
}

void lcd_command(uint8_t cmd){
  lcd_send(cmd, 0);
}

void lcd_data(uint8_t data){
  lcd_send(data, 1);
}

bool checkBS(){
    to_send &= ~(1 << RS);
    to_send |= (1 << RW); 
    PCF8574_Write(to_send);

    to_send |= (1<<EN);
    PCF8574_Write(to_send);
    _delay_us(1);

    bool busy = (PCF8574_Read() & (1 << D7));
    to_send &= ~(1<<EN);
    PCF8574_Write(to_send);

     to_send |= (1<<EN);
     PCF8574_Write(to_send);
     _delay_us(1);
     to_send &= ~(1<<EN);
     PCF8574_Write(to_send);

    to_send &= ~(1 << RW);
    PCF8574_Write(to_send);

    return busy;
}

void wait_until_BS(){
  while(checkBS()==1){
    _delay_us(1);
  }
}

void lcd_init(){
  _delay_ms(40);

  to_send = 0b00000011 << 4;
  lcd_enable();
  _delay_ms(5);
  
  lcd_enable();
  _delay_us(150);

  lcd_enable();
  wait_until_BS();
  
  to_send = 0b00000010 << 4;
  lcd_enable();
  wait_until_BS();
  
  lcd_command(0b00101000); 
  lcd_command(0b00001100);
  lcd_command(0b00000001);

  lcd_command(0b00000110);
}

void lcd_set_cursor(uint8_t row, uint8_t col){
  uint8_t pos = 0;
  if(row==0) pos = col;
  else pos = 0b01000000 + col;
  lcd_command(0b10000000 | pos);
}

void lcd_print(const char *str) {
    while (*str) {
        lcd_data(*str++);
    }
}

void timer1_init(){
  TCCR1B |= (1<<WGM12)|(1<<CS12)|(1<<CS10); 
  OCR1A = 15624; 
  TIMSK1 |= (1<<OCIE1A);
  sei();
}

int main() {
    I2C_Init();
    lcd_init();
    timer1_init();
    
    lcd_set_cursor(0, 0);
    lcd_print("Hello World");

    char buffer[16];
    while (1) {
      lcd_set_cursor(1,0);
      sprintf(buffer, "%u", seconds);
      lcd_print(buffer);
    }

    return 0;
}
ISR(TIMER1_COMPA_vect){
  seconds++;
}

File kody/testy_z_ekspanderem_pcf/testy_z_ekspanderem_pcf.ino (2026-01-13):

#include <avr/io.h>
#include <util/delay.h>

// Adres PCF8574N (ustawiony wedlug ustawienia pinow A0, A1, A2 na układzie)
#define PCF8574_ADDRESS 0x20

//Definicje pinow uzytych w PCF8574
#define D0 0 //P0
#define D1 1
#define D2 2
#define D3 3
#define D4 4
#define D5 5
#define D6 6
#define D7 7 //P7

// Funkcja inicjalizujaca magistralę I2C
void I2C_Init() {
    // Ustawienie predkosci magistrali I2C na 100kHz (dla zegara 16MHz)
    TWSR = 0x00; // Preskaler = 1
    TWBR = 0x48; // Predkosc = 16MHz / (16 + 2*TWBR*Prescaler) -> 100kHz
    TWCR = (1 << TWEN); // Wlaczenie TWI
}

// Funkcja rozpoczęcia transmisji I2C
void I2C_Start() {
    TWCR = (1 << TWSTA) | (1 << TWEN) | (1 << TWINT); // Start
    while (!(TWCR & (1 << TWINT))); // Czekaj na zakonczenie transmisji
}

// Funkcja zatrzymania transmisji I2C
void I2C_Stop() {
    TWCR = (1 << TWSTO) | (1 << TWEN) | (1 << TWINT); // Stop
}

// Funkcja wysyłania danych przez I2C
void I2C_Write(uint8_t data) {
    TWDR = data; // Ładuj dane do rejestru
    TWCR = (1 << TWEN) | (1 << TWINT); // Rozpocznij transmisje
    while (!(TWCR & (1 << TWINT))); // Czekaj na zakonczenie transmisji
}

// Funkcja komunikacji z PCF8574 - zapis wartosci na piny
void PCF8574_Write(uint8_t data) {
    I2C_Start();
    I2C_Write(PCF8574_ADDRESS << 1); // wyslanie adresu ukladu z bitem zapisu (R/W = 0)
    I2C_Write(data);                 // wyslanie danych
    I2C_Stop();
    
}

//Funkcja komunikacji z PCF8574 - odczyt wartosci z pinow
uint8_t PCF8574_Read() { 
    uint8_t data;
    I2C_Start();
    I2C_Write((PCF8574_ADDRESS << 1) | 1); // wyslanie adresu ukladu z bitem odczytu (R/W = 1)
    TWCR = (1 << TWEN) | (1 << TWINT);     // oczekiwanie na dane
    while (!(TWCR & (1 << TWINT)));
    data = TWDR;                           // pobranie danych
    I2C_Stop();
    return data;
}

//Funkcja glowna
int main() {
    I2C_Init();

    while (1) {
      PCF8574_Write(1<<D0);
      _delay_ms(200);
      PCF8574_Write(0<<D0);
      _delay_ms(200);
    }

    return 0;
}
